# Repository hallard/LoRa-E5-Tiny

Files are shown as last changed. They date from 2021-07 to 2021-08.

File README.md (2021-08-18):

# LoRa-E5-Tiny

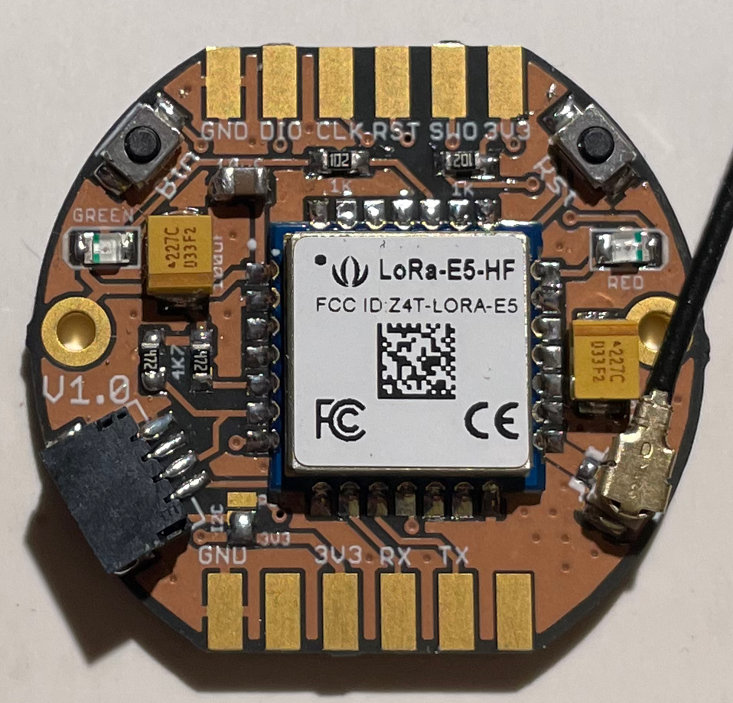
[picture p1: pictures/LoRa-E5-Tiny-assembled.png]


Based on [LoRa-E5](https://www.seeedstudio.com/LoRa-E5-Wireless-Module-p-4745.html) from Seedstudio, but I wanted something really Tiny so I removed loy of stuff and left only JTAG prog, Serial and I2C Stemma QWIIC connector, and of course cell coin handler.

> :eyes: take a look on this excellent [reading](https://www.rs-online.com/designspark/can-i-prolong-my-coin-cell-battery-life-with-a-capacitor) on how to use capacitor to prolong cell coin batteries and understand the risk. I will use for EU8868 so for peaks approx 40mA, 3 times less than in the article so I guess it could works with 2 x 220uF or 470uF capacitors. Challenge would be to find them in 1206 footprint format.

I'm using mainly to flash custom firmware in it, and not using AT default firmware.

> :warning: **These boards have been received** they works as expected but stil not tried with cell coin powering

## Challenges

With this consumption [issue](https://forum.rakwireless.com/t/rak3172-too-much-consumption-in-transmit-eu868/4781) discovered on LoRa-E5 boards (but also on RAK3172) I'm not confident it will works on Cell Coin CR2450 battery even if I added 2 330uF capacitors on 3.3V rail.

## Features

- LoRa-E5 Module
- FTDI SMD 6 pads edge connector (:warning: **use 3.3V FTDI One, not 5V**)
- JTAG SMD 6 pads edge connector to flash module (PA13-SWDIO / PA14-SWCLK / PB3-SWO / RESET)
- Green Led on PB13
- Red Led on PA9
- 2 Tactile Switches (boot and reset)
- u-FL Antenna connector
- Stemma QWIIC I2C connector
- 2 x 1206 footprint for big capacitors see [reading](https://www.rs-online.com/designspark/can-i-prolong-my-coin-cell-battery-life-with-a-capacitor)
- CR2450 Cell coin battery size
- CR2450 battery holder

## Detailed Description

No specific documentation for now, it's just a kind of wiring helper as schematic.

I also assume that you are familiar with all LoRaWAN stuff, all setup/infrastructure/network server/provisionning and other are out of scope of this repository.

## Schematics

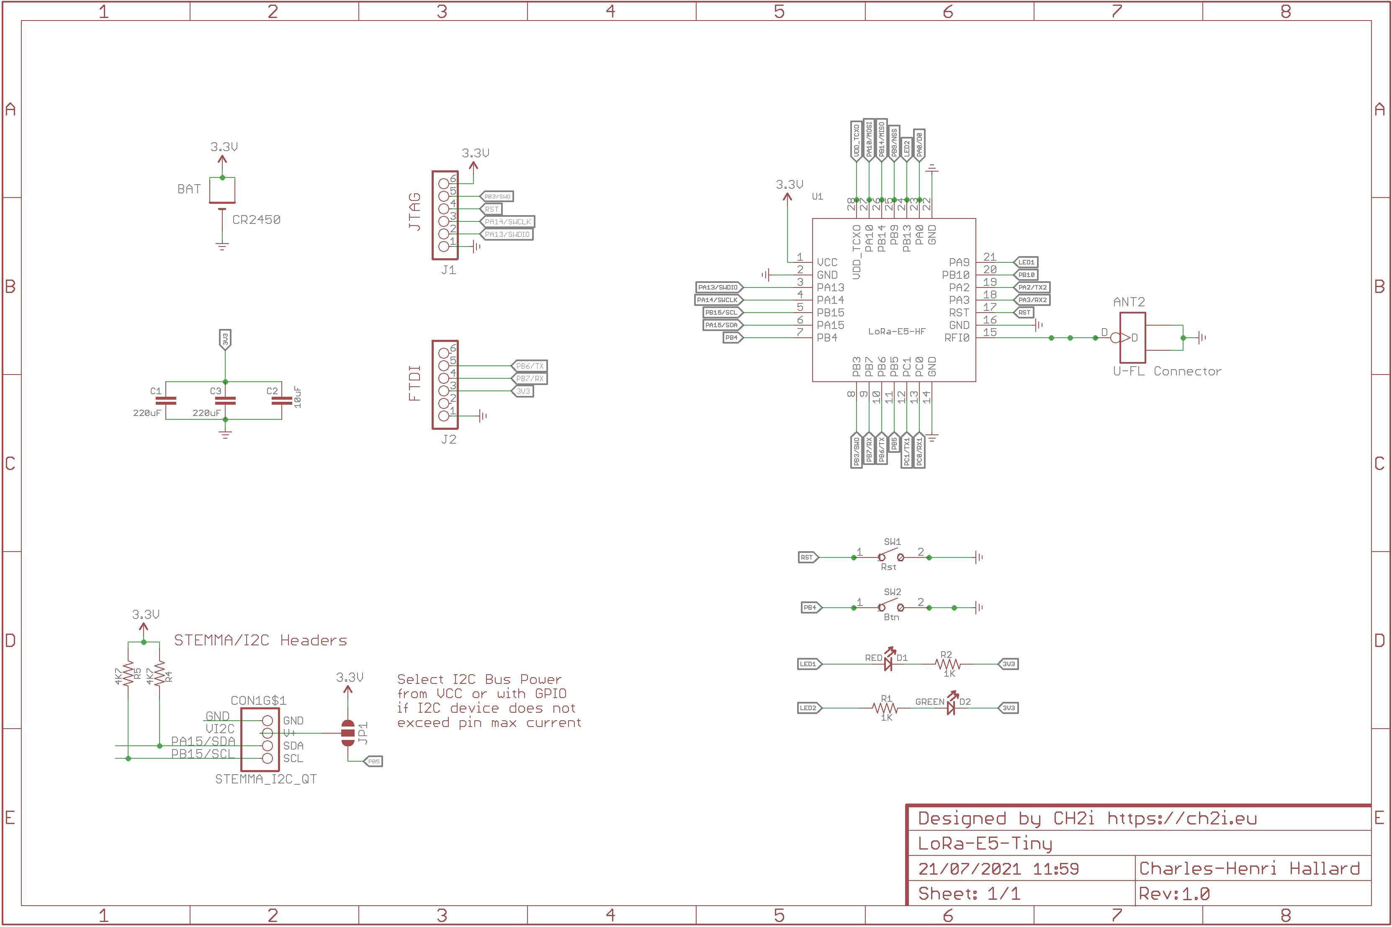
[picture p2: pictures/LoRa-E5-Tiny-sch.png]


## Boards 

You can order board on [oshpark](https://oshpark.com). 

- [V1.0](https://oshpark.com/shared_projects/xUa1Y94Z) 

It's a pitty after several discuss with OSHPark that I can't have any rewards for each people ordering my boards, this would allow me to order free PCB for shared projects and create new ones. For information my shared boards generated a total of **$285 162.00** orders at PCBs.io in 4 years, not bad at all :-), but looks like they have gone :sob:

Hoping one day OSHparks will thanks me giving them this market. 

### Assembled boards

**Top & bottom side V1.0**

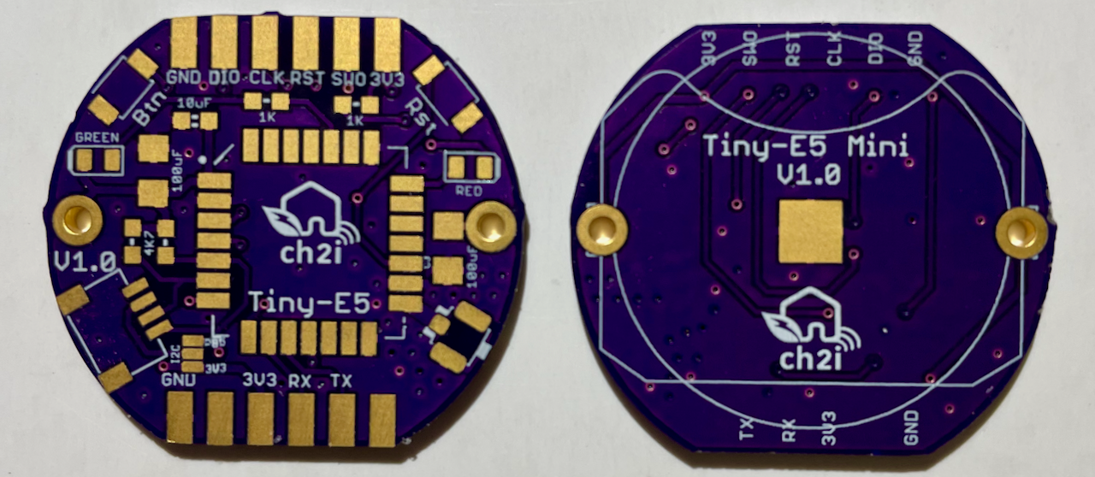
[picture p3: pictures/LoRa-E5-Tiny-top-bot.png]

<!--
<img src="https://github.com/hallard/LoRa-E5-Tiny/blob/main/pictures/LoRa-E5-Tiny-top.png">
<img src="https://github.com/hallard/LoRa-E5-Tiny/blob/main/pictures/LoRa-E5-Tiny-bot.png">
-->

### Bill Of Material

Nothing fancy, due to size constraint, components are 0603/1206 and can be ordered almost anywhere (digikey, mouser, radiospare, ...). 
use only what you need dependings on what you want to do. 

> :memo: I2C pullup may not needed, most QWIIC/Steamma boards have their own. 

Check Seeed format [BOM](https://github.com/hallard/LoRa-E5-Tiny/blob/main/LoRa-E5-Tiny-BOM.xlsx) File, check on [Seeed OPL](https://www.seeedstudio.com/opl.html) for manufacturer SKU match.

### Test Board out of factory stock 

When the boards are from factory, default AT firmware is flashed and thus we have the possibility to test the board before flashing custom firmware and maily also get defaults keys from device.

To do so, connect a 3V3 FTDI Type USB/Serial to access Serial Console 

> :warning: **Do not use 5V configured FTDI** 

I personnaly use these one for [Sparkun](https://www.sparkfun.com/products/14050) but you can find clones anywhere on the Web.



Once done open Serial terminal (the one from FTDI Serial Port) configured as `9600` BPS `8N1`, no flow control, echo typed characters and set to CR+LF for enter key, press reset button and you should be able to see banner

- Connect FTDI on the 6 pins edge header of the board (if PCB is 2mm thickness should works without soldering)
- use them a terminal application and open the port on your computer corresponding to the FTDI device
- set terminal settings to 9600 bauds 8 bits no parity 1 stop bit (8N1)

Once done open Serial terminal (the one from FTDI Serial Port) configured as `9600` BPS `8N1`, no flow control, echo typed characters and set to CR+LF for enter key

Then type `AT` command to see if the LoRa board answer, in this example the board answered `+AT: OK` which is correct
```
AT 
+AT: OK
```

Now get the device version
```
AT+VER 
+VER: 4.0.11
```

Now get the device information 
```
AT+ID  
+ID: DevAddr, 24:90:08:93
+ID: DevEui, 2C:F7:F1:20:24:90:08:93
+ID: AppEui, 80:00:00:00:00:00:00:06
```

I'm using [TTN](https://www.thethingsnetwork.org/) for testing so please follow excellent RAK guide on how to provision your device onto TTN [here](https://docs.rakwireless.com/Product-Categories/WisDuo/RAK3172-Module/Quickstart/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)

In our case we will use the AppKey generated from TTN when provisionning device, just provision your device onto TTN, get the key and put into the device as follow with command `AT+KEY=APPKEY` in our case AppKey is `B7536DCEFB1EBC4AB9871293F6FA7DB5`
```
AT+KEY=APPKEY,"B7536DCEFB1EBC4AB9871293F6FA7DB5" 
+KEY: APPKEY B7536DCEFB1EBC4AB9871293F6FA7DB5
```

Set ADR + Frequency Plan EU868 + OTAA
```
AT+ADR=ON   
+ADR: ON
AT+DR=EU868  
+DR: EU868
AT+MODE=LWOTAA 
+MODE: LWOTAA
```

Check Frequency Plan
```
AT+DR=SCHEME 
+DR: EU868
+DR: EU868 DR0  SF12 BW125K 
+DR: EU868 DR1  SF11 BW125K 
+DR: EU868 DR2  SF10 BW125K 
+DR: EU868 DR3  SF9  BW125K 
+DR: EU868 DR4  SF8  BW125K 
+DR: EU868 DR5  SF7  BW125K 
+DR: EU868 DR6  SF7  BW250K 
+DR: EU868 DR7  FSK  50kbps 
+DR: EU868 DR8  RFU
+DR: EU868 DR9  RFU
+DR: EU868 DR10 RFU
+DR: EU868 DR11 RFU
+DR: EU868 DR12 RFU
+DR: EU868 DR13 RFU
+DR: EU868 DR14 RFU
+DR: EU868 DR15 RFU
```

Now time to join (be sure device is provisioned on TTN and you have a TTN gateway around)
```
AT+JOIN 
+JOIN: Start
+JOIN: NORMAL
+JOIN: Network joined
+JOIN: NetID 000013 DevAddr 26:0B:63:94
+JOIN: Done
```

Now send confirmed Hello World message
```
AT+CMSG="Hello World"  
+CMSG: Start
+CMSG: Wait ACK
+CMSG: FPENDING
+CMSG: ACK Received
+CMSG: RXWIN1, RSSI -40, SNR 5.0
+CMSG: Done
```

### Compile and flash Firmware

You can flash the board with excellent [mbed-os](https://os.mbed.com/mbed-os/) framework. 
Easy way is to use [mbed studio IDE](https://os.mbed.com/studio/). 
We added this board into [stm32customtargets](https://github.com/ARMmbed/stm32customtargets), don't hesitate to read the [readme](https://github.com/ARMmbed/stm32customtargets/blob/master/README.md). 
Finally the main firmware [mbed-os-example-lorawan](https://github.com/ARMmbed/mbed-os-example-lorawan) program.

Once IDE installed: 

- use `file` / `import program` and them import the example with URL `https://github.com/ARMmbed/mbed-os-example-lorawan`
- right click in the project name and select `Add Library` and enter `https://github.com/ARMmbed/stm32customtargets`
- open the file `custom_targets.json` from folder `stm32customtargets` and copy whole contents
- paste copied contents in the main root folder file `custom_targets.json` (yes replace the whole file) 
- open the file `mbed_app.json` and change parameters on the section `target_overrides`
    - LoRaWAN parameters such as frequency plan, OTAA, Duty Cycle, ...
    - replace keys with the ones you got from above step `lora.device-eui`, `lora.application-eui` and `lora.application-key`
- add the following section near the end of the file `mbed_app.json`.

```json
        "LORA_E5_TINY": {
            "stm32wl-lora-driver.rf_switch_config": 2,
            "stm32wl-lora-driver.debug_rx": "LED1",
            "stm32wl-lora-driver.debug_tx": "LED2",
            "stm32wl-lora-driver.debug_invert": 1
        }
```

Then on IDE select target "LORA_E5_TINY", build and flash with your favorite programmer (I'm using STLink) with GND/SWDIO/SWDCLK/RESET connected. 

Pay attention, that 1st time you need to erase SeeeStudio original firmware, make sure the Read Out Protection of the device is AA. If it is shown as BB, select AA and click Apply. See the end of this [section](https://wiki.seeedstudio.com/LoRa_E5_Dev_Board/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) on how to do that with STM32CubeProgrammer.

### Build and Flash

From IDE you can build the example. If you plug your STLink while project opened, mbed ide will ask you if you want to set it up for this project/target, once approved you can compile, flash and even debug from mbed ide (need some tools installed, [read](https://os.mbed.com/docs/mbed-studio/current/monitor-debug/debugging-with-mbed-studio.html), very nice.

<!--<img src="https://github.com/hallard/LoRa-E5-Breakout/blob/main/pictures/mbed-ide.png">-->

You can also see logs with the FTDI adapter and any Serial terminal set to 115200 bauds 8 bits no parity 1 stop bit (8N1)

```
Mbed LoRaWANStack initialized 
 CONFIRMED message retries : 3 
 Adaptive data  rate (ADR) - Enabled 
 Connection - In Progress ...
 Connection - Successful 
 Dummy Sensor Value = 3 
 23 bytes scheduled for transmission 
 Message Sent to Network Server 
 Dummy Sensor Value = 5 
 23 bytes scheduled for transmission 
 Message Sent to Network Server 
 Dummy Sensor Value = 7 
 23 bytes scheduled for transmission 
```

Green LED will be on when on receive mode and Red when sending data.

## License

   

This work is licensed under a [Creative Commons Attribution-NonCommercial 4.0 International License](http://creativecommons.org/licenses/by-nc/4.0/)

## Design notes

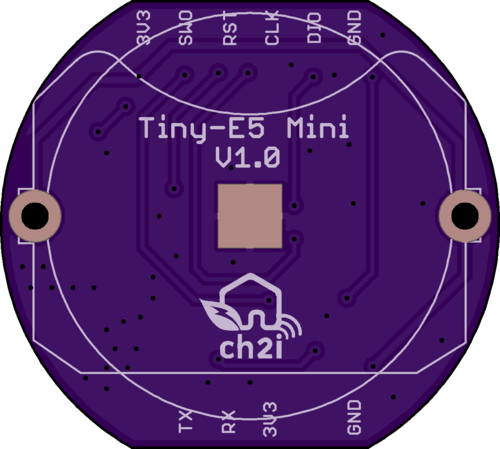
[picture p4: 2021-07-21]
pictures/LoRa-E5-Tiny-bot.png

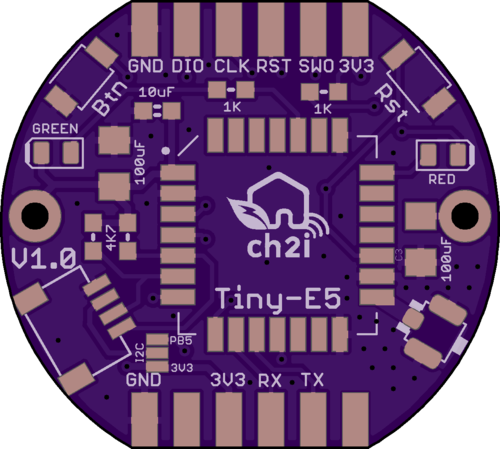
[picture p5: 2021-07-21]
pictures/LoRa-E5-Tiny-top.png

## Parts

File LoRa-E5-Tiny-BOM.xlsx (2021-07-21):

Designator | Seeed SKU | Manufacturer SKU | Qty | Description
U1 | 317990687 | 317990687 | 1 | LoRa-E5 STM32WLE5JC Module
C1 | 302010103 | CC0603KRX5R6BB106 | 1 | SMD CAP Ceramic 10uF-10V-10%-X5R-603
C2, C3 | 302010183 | GRM31CR60J107ME39L | 2 | SMD CAP Ceramic 100uF-6.3V-20%-X5R-1206
R4, R5 | 301010290 | RC0603JR-074K7L | 2 | SMD RES 4.7K-5%-1/10W-603
R1, R2 | 301010291 | RC0603JR-071KL | 2 | SMD RES 1K-5%-1/10W-0603
D2 | 304090043 | 19-217-G7C-AN1P2-3T | 1 | SMD LED Clear-Green
D1 | 304090042 | 19-217-R6C-AL1M2VY-3T | 1 | LED-SMD Red Diffused
K1,K2 | B3U-1000P | B3U-1000P-2P-SMD | 2 | Tactile Switch 3x2.5mm SMD
ANT | 320111077 | U.FL-R-SMT-1(10) | 1 | SMD U-FL Female CONN-Gold;3P-L2.6*W2.6*H1.25mm
C2, C3 | 302020027 | TAJD477M006RNJ | 2 | SMD CAP Tantalum 470uF-6.3V;D
 |  |  |  | Other try, or 220uF/330uF/470uF 1206

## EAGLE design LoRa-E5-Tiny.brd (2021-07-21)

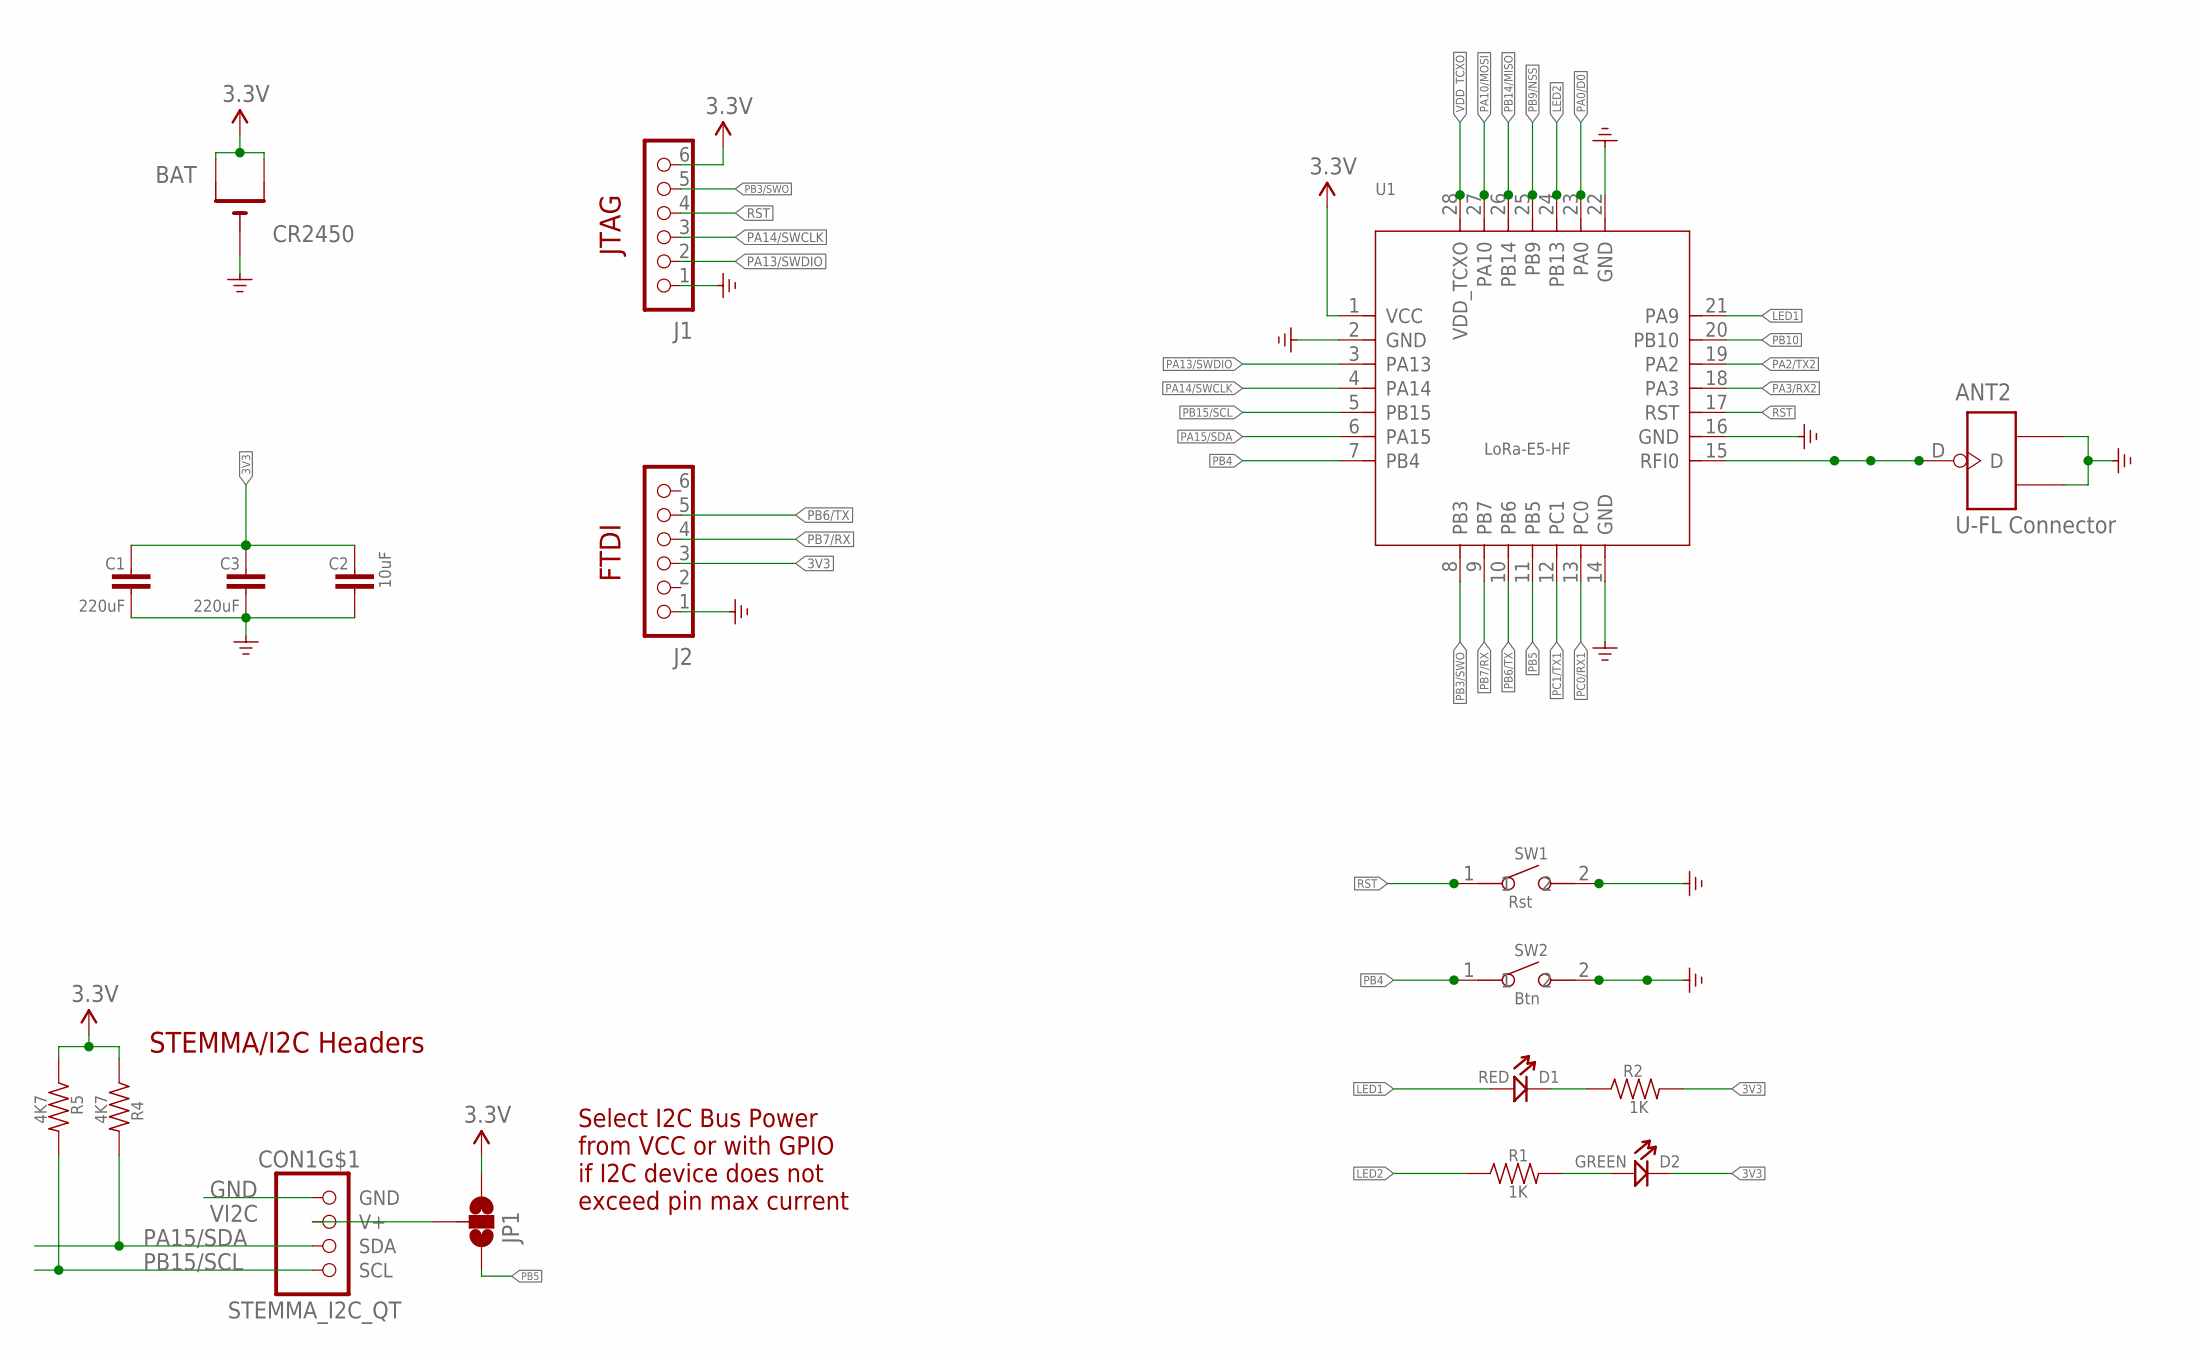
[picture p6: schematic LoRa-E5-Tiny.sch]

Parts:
ANT2: U-FL Connector; U-FL3P-SMD-2.6X2.6X1.0MM
BAT: CR2450; CR2450-THM
C1, C3: 220uF; 1206
C2: 10uF; 0603-CAP
CON1: STEMMA_I2C_QT; JST_SH4
D1: RED; LED-0805
D2: GREEN; LED-0805
J1: JTAG; M1X06_PAD
J2: FTDI; M1X06_PAD
JP1: JUMPER-SMT_3_NO_NO-SILK; SMT-JUMPER_3_NO_NO-SILK
R1, R2: 1K; 0603-RES
R4, R5: 4K7; 0603-RES
SW1: Rst; SW2-2.6-3.0X2.5X1.2+0.4MM
SW2: Btn; SW2-2.6-3.0X2.5X1.2+0.4MM
U1: LoRa-E5-HF; MOUDLE28P-1.25-12X12X2.5MM

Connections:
3V3: BAT.+1 (+), BAT.+2 (+1), C1.2, C2.2, C3.2, D2.-, J1.6, J2.3, JP1.1, R2.2, R4.1, R5.1, U1.1 (VCC)
GND: ANT2.GND1, ANT2.GND2, BAT.GND (-), C1.1, C2.1, C3.1, CON1.1 (GND), J1.1, J2.1, SW1.2, SW2.2, U1.2 (GND), U1.14 (GND), U1.16 (GND), U1.22 (GND)
LED1: D1.+, U1.21 (PA9)
LED2: R1.1, U1.24 (PB13)
unnamed: D2.+, R1.2
unnamed: D1.-, R2.1
PA0/D0: U1.23 (PA0)
PA2/TX2: U1.19 (PA2)
PA3/RX2: U1.18 (PA3)
PA10/MOSI: U1.27 (PA10)
PA13/SWDIO: J1.2, U1.3 (PA13)
PA14/SWCLK: J1.3, U1.4 (PA14)
PA15/SDA: CON1.3 (SDA), R4.2, U1.6 (PA15)
PB3/SWO: J1.5, U1.8 (PB3)
PB4: SW2.1, U1.7 (PB4)
PB5: JP1.3, U1.11 (PB5)
PB6/TX: J2.5, U1.10 (PB6)
PB7/RX: J2.4, U1.9 (PB7)
PB9/NSS: U1.25 (PB9)
PB10: U1.20 (PB10)
PB14/MISO: U1.26 (PB14)
PB15/SCL: CON1.4 (SCL), R5.2, U1.5 (PB15)
PC0/RX1: U1.13 (PC0)
PC1/TX1: U1.12 (PC1)
RF: ANT2.D, U1.15 (RFI0)
RST: J1.4, SW1.1, U1.17 (RST)
VDD_TCXO: U1.28 (VDD_TCXO)
VI2C: CON1.2 (V+), JP1.2

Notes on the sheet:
STEMMA/I2C Headers
JTAG
FTDI
Select I2C Bus Power from VCC or with GPIO if I2C device does not exceed pin max current

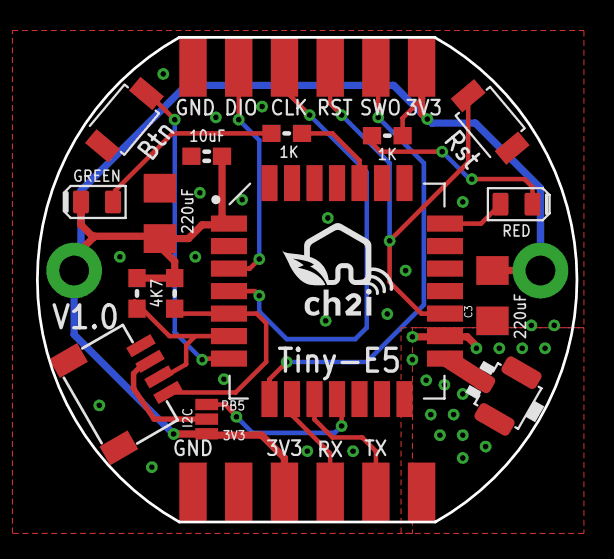
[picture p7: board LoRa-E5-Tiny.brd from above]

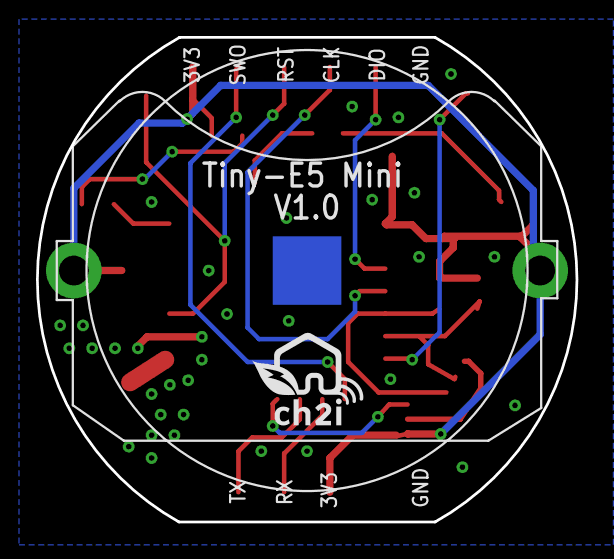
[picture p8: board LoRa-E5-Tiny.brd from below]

Board: 2 copper layers, 30.0 x 26.9 mm, 20 parts (2 on the bottom side), 18 nets.

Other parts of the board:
U$1, U$2: LOGO_C2I_015

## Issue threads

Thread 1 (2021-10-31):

Coin cell operation

eivholt, 2021-10-31:
Thanks for sharing this tiny board, I plan to base a project on it. I was reading about the peak current draw and was wondering if you have made any progress on experimentation running the circuit on coin cell battery? I recently got a Lora E5 module and have started profiling using Otii Arc. I will post an update on my findings using coin cell and capacitors.

eivholt, 2021-11-01:
As a start I got pretty much the same current consumption at TX using the Lora-E5-mini, using AT-commands and the supplied whip antenna. Will proceed to flash custom program using mbed and try to apply the suggested TX-parameters.

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

eivholt, 2021-11-04:
I believe I have hit the desired TX amplification. Not sure about actual signal reduction, whether it will be a problem for my application. I have a gateway in my house so I need to do some field testing. Here are the stats from my gateway:

rssi": -61,
"channel_rssi": -61,
"snr": 7.5,
"bandwidth": 125000,
"spreading_factor": 7

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

I will move forward with running on a custom PCB and experiment with coin cell operation.

Thank you so much for sharing your work, you are a true legend!

hallard, 2021-11-05:
@eivholt thanks for your feedback,

Changing TX according datasheet reduce consumption but a user saw range decrease
https://forum.seeedstudio.com/t/lora-e5-fw-bug-tx-eu868-85ma-too-high-consumption/260126

So not sure what to do, what is real is that this module (same for RAK) as not been designed for low power on EU868, so that's really a shame. Nothing to do until hardware changes on modules.

Let me know your testings, very interesting.

SRSchwab, 2023-04-12:
@eivholt Does RAK3172-SiP WisDuo LPWAN SiP solve the issue?

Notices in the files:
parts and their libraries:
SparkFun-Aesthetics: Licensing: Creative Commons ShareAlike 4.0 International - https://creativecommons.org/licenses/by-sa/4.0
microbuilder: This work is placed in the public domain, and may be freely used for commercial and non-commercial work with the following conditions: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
